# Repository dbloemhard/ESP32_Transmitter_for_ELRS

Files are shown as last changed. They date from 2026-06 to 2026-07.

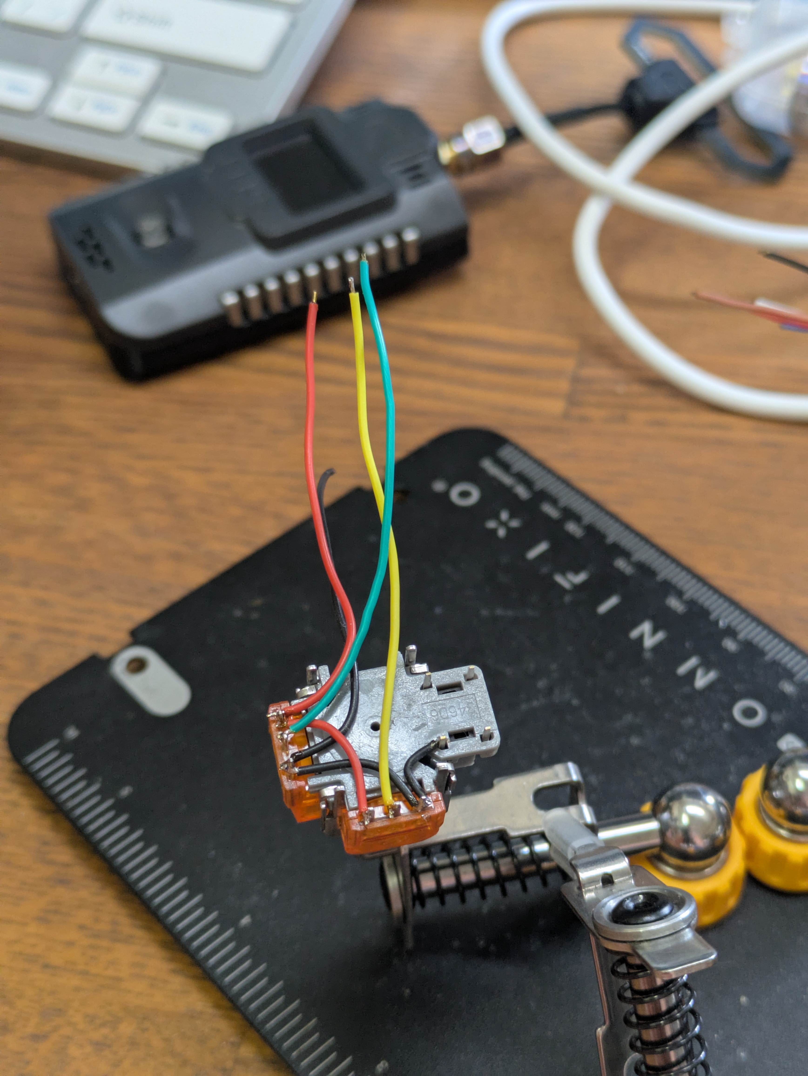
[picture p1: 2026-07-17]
Assets/Joystick Wiring 5.jpg

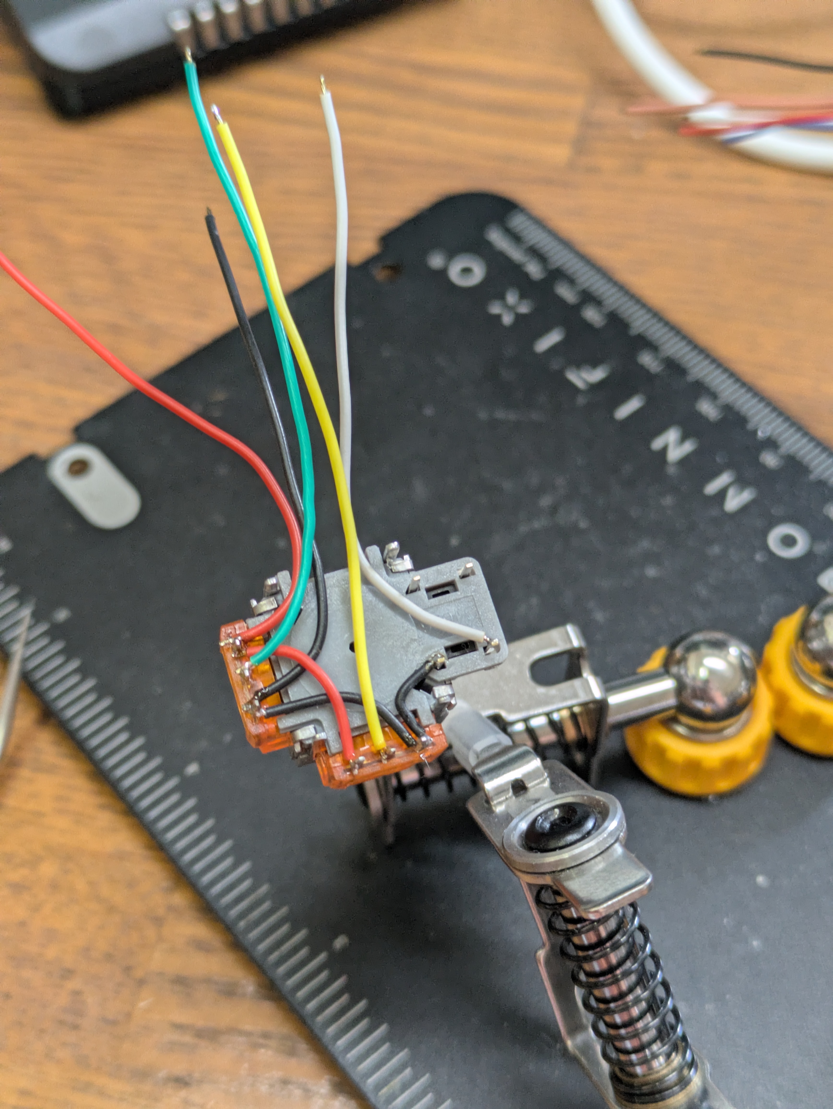
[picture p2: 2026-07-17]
Assets/Joystick Wiring 6.jpg

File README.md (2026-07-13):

# ESP32 C3 Nano TX


ESP32 C3 Nano sized ExpressLRS transmitter originally based on the Simple TX Arduino Transmitter project, with a few extra features.

Simple TX is an Arduino based ELRS RC transmitter TX by Kkbin505. He designed an RC transmitter (soft and hardware) that is simple to build, and use.

I am rewriting it to run on an ESP32 C3. This has an OLED screen and is small enough to make my TinyTX project even smaller. I am reading telemetry from the ELRS module and implemented the full ELRS Lua script for configuring ELRS as well as the handset.

# THIS IS A W.I.P.
https://youtube.com/shorts/-rPwNI36CTY?feature=share

The radio works, and i have flown around my room with it. ELRS transmitter telemetry is working, and the configuration menu is usable to change ELRS settings. Version 3 of the 3D print finally fits everything and can be screwed together using m1.2x6 whoop canopy screws. From here on in its mainly going to be code bug fixes, and maybe i'll come up with another 3d print design.

Currently outstanding code tasks:
* Bluetooth joystick using ESP32-BLE-Gamepad library (RX as a TX does not suport BLE Joystick so need to implement it myself)
* Multitask the OLED updates to free up more time for the ELRS code
* ~~Bluetooth transmitter?? Connect bluetooth joysticks to this device and forward controls to the ELRS transmitter~~ Unfortunately most game controllers use full bluetooth which is only supported on the original ESP32, not the C3

Programmed in Arduino IDE with love and a some AI suggestions (found myself rewriting everything it did). 
1. Install the ESP32 Boards via board manager
2. then select ESP32C3 Dev Module board
3. USB CDC On Boot "Enabled"
4. Build and upload.

# Features:
- Fits in your pocket. Not like the Radio Master Pocket which will get you funny looks... Actually pocketable.
- Using PS5 hall sensor joysticks so you dont miss out on that super magnetic accuracy even at this size.
- 0.42" OLED screen with easy to read, simple display
- Runs on a 1s lipo battery - the same as you fly your whoops with. Have not tested but expect more than 1hr runtime with a  1s 300mah
- Designed to use a 100mw telemetry Nano receiver as a TX module (RX as a TX). Also support ExpressLRS 2.4G external TX modules, but that would probably be bigger than the radio itself. External modules would need a separate power supply as most are designed to work on 7v+
- Up to 500Hz packet rate. Possibly even FLRC 1000hz? Who even uses that...
- 4 analog channels
- 3 AUX channels selectable via joystick button presses (left joystick button toggles Arm, right joystick button toggles channel 6, long press for channel 7)

Current STL is basic, and a tight fit. Make sure all wires are as short as needed, trim as necessary. I will be designing a PCB board you can order from PCBWay or whatever that will make building this a 15 minute job. But for now its manual wiring. 

# Parts list:
* ESP32 C3 with Oled https://ja.aliexpress.com/item/1005009157602185.html
* PS5 Joysticks https://ja.aliexpress.com/item/1005006282848536.html
* Nano receiver to be used as TX module https://ja.aliexpress.com/item/1005010228737836.html?
* 5V boost converter: https://ja.aliexpress.com/item/1005011803028198.html
* Also need two resistors for a voltage divider circuit (16k and 33k), silicone wires, battery pigtail, and a 3D printed case (joystick covers can be printed or bought)
Total cost is around $15-20

Based on work by kkbin505 with his SimpleTX project, but is now almost completely rewritten, 90% by hand (LLMs only used for code suggestions)
 * This project is distributed in the hope that it will be useful, but WITHOUT ANY WARRANTY.

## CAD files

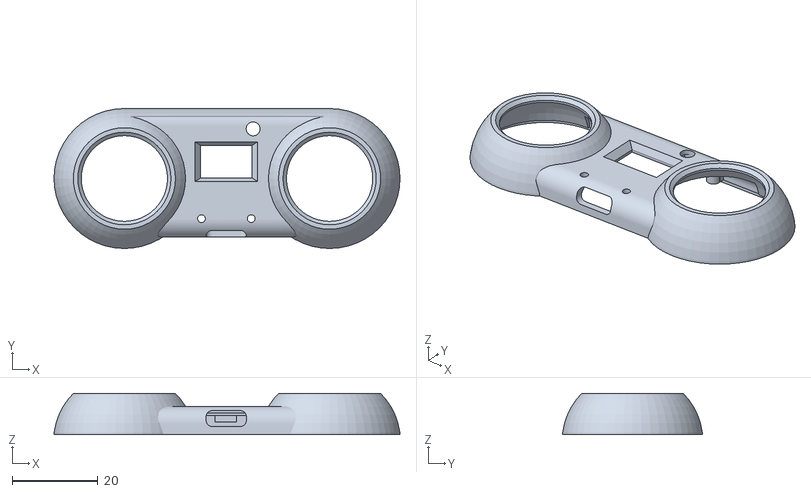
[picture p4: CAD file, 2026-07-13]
Assets/NanoTX Top 3.stl
80.8 x 32.7 x 9.60

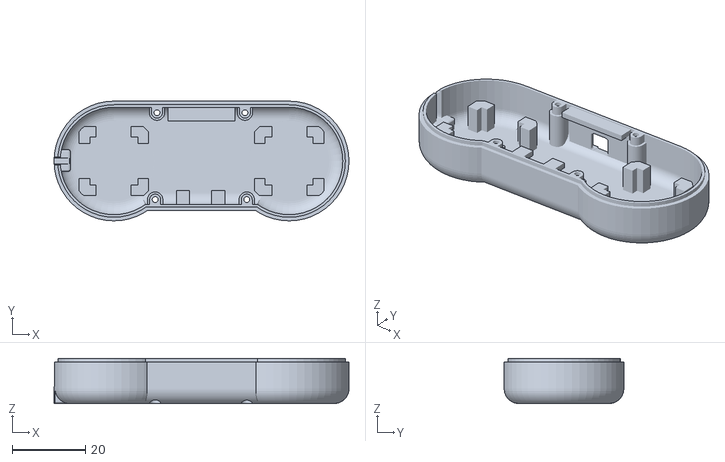
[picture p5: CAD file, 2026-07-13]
Assets/NanoTX Bottom 3.stl
80.8 x 32.8 x 12.4

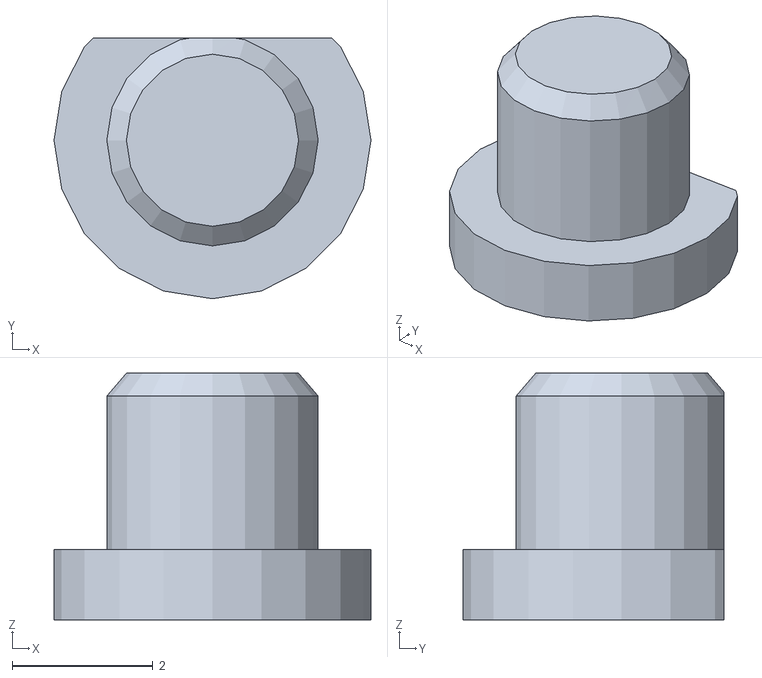
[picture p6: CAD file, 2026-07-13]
Assets/NanoTX Button 3.stl
4.50 x 3.70 x 3.50

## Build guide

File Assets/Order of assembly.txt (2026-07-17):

NanoTX assembly:
-------------------
a. First flash your ELRS receiver to be a transmitter. 
Connect it up to a flight controller, or USB-TTL
Go to https://expresslrs.github.io/web-flasher/ and select Receiver.
Follow normal instructions, most this size will be the Betafpv Nano 2.4Ghz FW
On the Options screen, select Advanced and select "Flash RX as a TX (full duplex internal module only)
Follow other flashing options as normal.
b. Next flash the ESP32 with my firmware. This is coded in Arduino studio so you will need that, as well as the ESP32 library, U8G2 library.
c. Solder the parts together.
--------------------
1. Mock up gimbal distances to know how long to trim the wires before attaching to the ESP32
2. Ditto for the ELRS receiver and 5v regulator
3. ELRS receiver (TX Module) is double-sided taped to the back shell of the housing
4. ELRS antenna is fed through the hole at the top and attached to the receiver (TX Module). It should make a little loop to have some slack.
5. 5V regulator (Shrink wrapped) goes next. It is sandwiched between the receiver and ESP32 - doesn't need tape
6. ESP32 should sit on top of the print without too much pressure needed to push it against the shelves it will sit on. Wires should be tucked in the gap under the ESP32 - the joystick caps will come within 0.5mm of the ESP32 so it is important that all wires are within the bounds of the ESP32 PCB

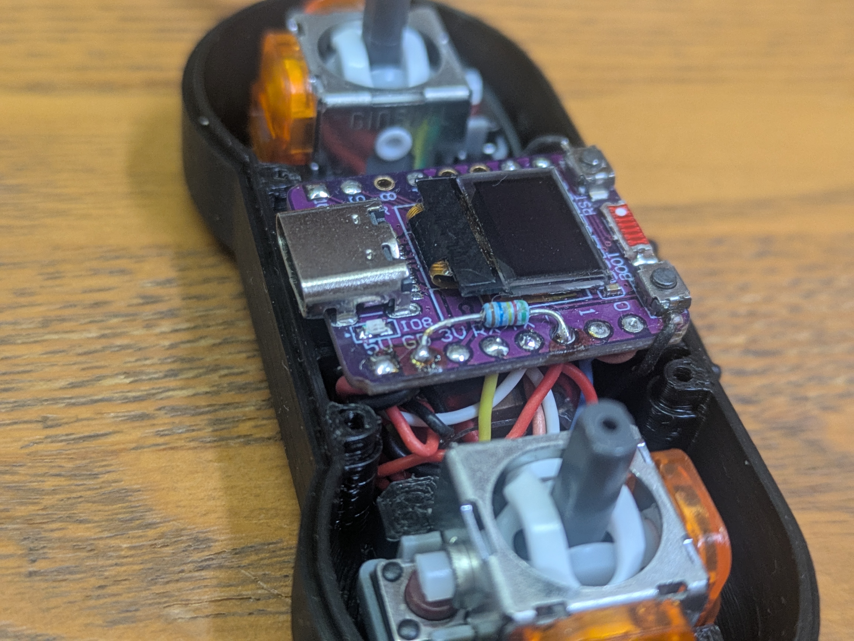
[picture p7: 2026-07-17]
Assets/Ready for Assembly 2.jpg

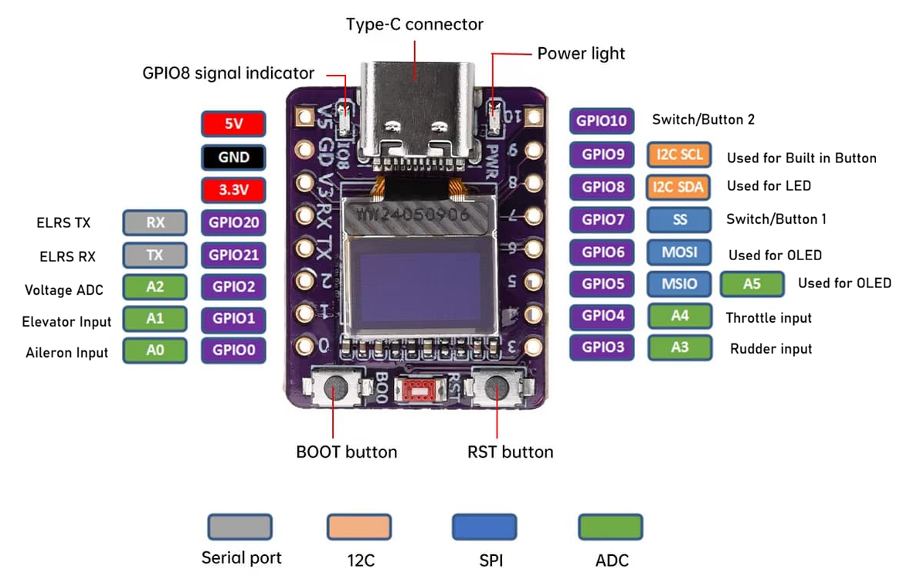
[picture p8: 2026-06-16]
Assets/Wiring Diagram.png

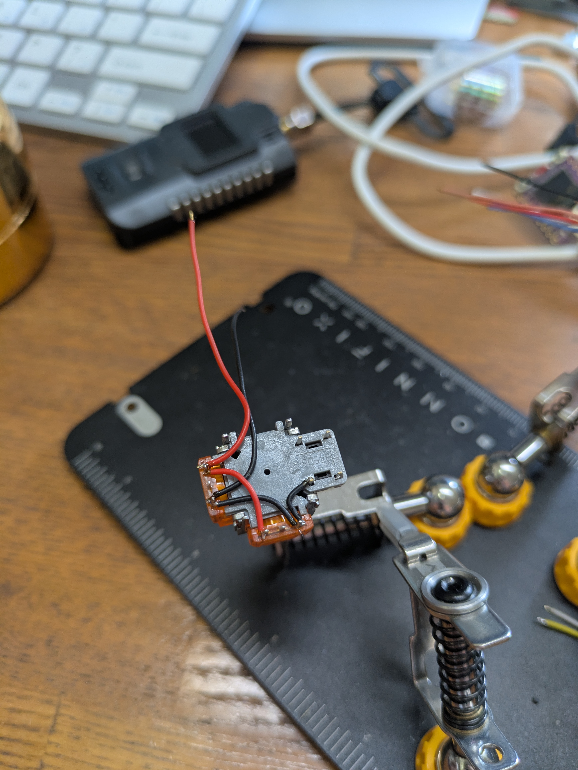
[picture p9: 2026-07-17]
Assets/Joystick Wiring 4.jpg

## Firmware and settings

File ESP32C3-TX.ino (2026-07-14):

/*
// Simple ESP32 C3 transmitter
// ESP32 C3 0.42" OLED
// ELRS 2.4G NANO RX as a TX module
// Based on SimpleTX by kkbin505
// https://github.com/kkbin505/Arduino-Transmitter-for-ELRS

 * This file is part of ESP32C3-TX
 *
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
 * ESP32C3-TX is distributed in the hope that it will be useful,
 * but WITHOUT ANY WARRANTY; without even the implied warranty of
 * MERCHANTABILITY or FITNESS FOR A PARTICULAR PURPOSE.  See the
 * GNU General Public License for more details.
 * <http://www.gnu.org/licenses/>.
 */

#include <Arduino.h>
#include <Preferences.h>
#include "hardware.h"
#include "config.h"
#include "crsf.h"
#include "elrs.h"
#include "oled.h"

//#define DEBUG // if not commented out, Serial.print() is active! For debugging only!!
//#define TIMINGDEBUG  // When this is active Serial port will print out timing details

//----- global variables for inputs -------------------
struct InputValues {
    int32_t leftX;
    int32_t leftY;
    int32_t rightX;
    int32_t rightY;
    int16_t AUX1;
    int16_t AUX2;
    int16_t AUX3;
};
InputValues stickValues;

struct ADCValues {
    int32_t leftX;
    int32_t leftY;
    int32_t rightX;
    int32_t rightY;
    int32_t voltage;
};
ADCValues rawValues;

struct FilterState {
    int32_t rightX;
    int32_t rightY;
    int32_t leftY;
    int32_t leftX;
};
FilterState filteredRaw;

float batteryVoltage;

bool ARMED = false;

// 0 = No move/button
// 1 = Up
// 2 = Down
// 3 = Left
// 4 = Right
// 5 = Joystick button
// 6 = Built in button (short press)
// 7 = Built in button (long press)
uint8_t navigate = 0;

//----- function headers ----------------------------------
inline int32_t lowLatencyFilter(int32_t currentRaw, int32_t *previousFiltered);
int16_t calibrate(int16_t raw, int16_t minVal, int16_t centerVal, int16_t maxVal);
int32_t applyCyclicExpo(int32_t stickDiff, uint8_t expoFactor);
int32_t applyThrottleExpo(int32_t adcVal, uint8_t expoFactor);
uint16_t processStick(int32_t adcValue, uint8_t chIndex);
void mapChannels();
void getAnalogInputs();
void getDigitalInputs();
void checkGestureSetting();
bool checkStickMove();
void playTone(uint8_t timesPerSecond);
void blinkLED(int ledPin, uint16_t blinkRate);
void stickMenuNavigation();
void statusDisplay();
void logData();

//----- global variables for ELRS -------------------------
int16_t rcChannels[CRSF_MAX_CHANNEL];
CRSF crsfClass;
// Instantiate ELRS (Module) class, passing CRSF driver object to it
ELRS elrsClass(crsfClass);

// -----------------------------------------------------------------------------------------------------
// Calibration functions
// -----------------------------------------------------------------------------------------------------
void calibrationLoad();
void calibrationSave();
void calibrationChirp(uint8_t times);
bool calibrationRun();

Preferences prefs;
#define CALIB_CENT_TMO  5000    //ms
#define CALIB_MOVE_TMO  15000   // ms
bool calibrationRequested=false;
uint32_t calibrationTimerStart;
int      cal_reset = 0 ;

struct CalibValues {
    int rightXMin  = 0;
    int rightXMax  = 4095;
    int rightXMid  = 2048;
    int rightYMin  = 0;
    int rightYMax  = 4095;
    int rightYMid  = 2048;
    int leftXMin   = 0;
    int leftXMax   = 4095;
    int leftXMid   = 2048;
    int leftYMin   = 0;
    int leftYMax   = 4095;
    int leftYMid   = 2048;
};
CalibValues calValues;

void calibrationSave() {
    // Open the "gimbal" namespace in Read-Write mode (false)
    prefs.begin("gimbal", false);
    
    prefs.putShort("rightXMin",  calValues.rightXMin);
    prefs.putShort("rightXMid", calValues.rightXMid);
    prefs.putShort("rightXMax",  calValues.rightXMax);
    
    prefs.putShort("rightYMin",  calValues.rightYMin);
    prefs.putShort("rightYMid", calValues.rightYMid);
    prefs.putShort("rightYMax",  calValues.rightYMax);
    
    prefs.putShort("leftXMin",  calValues.leftXMin);
    prefs.putShort("leftXMid", calValues.leftXMid);
    prefs.putShort("leftXMax",  calValues.leftXMax);

    prefs.putShort("leftYMin",  calValues.leftYMin);
    prefs.putShort("leftYMid",  calValues.leftYMid);
    prefs.putShort("leftYMax",  calValues.leftYMax);
        
    prefs.end();
}

void calibrationLoad() {
    // Open the "gimbal" namespace in Read-Only mode
    prefs.begin("gimbal", true);
    
    // Read values, providing safe defaults if no data has been saved yet
    calValues.rightXMin = prefs.getShort("rightXMin", 0);
    calValues.rightXMid = prefs.getShort("rightXMid", 2048);
    calValues.rightXMax = prefs.getShort("rightXMax", 4095);
    
    calValues.rightYMin = prefs.getShort("rightYMin", 0);
    calValues.rightYMid = prefs.getShort("rightYMid", 2048);
    calValues.rightYMax = prefs.getShort("rightYMax", 4095);
    
    calValues.leftXMin  = prefs.getShort("leftXMin", 0);
    calValues.leftXMid  = prefs.getShort("leftXMid", 2048);
    calValues.leftXMax  = prefs.getShort("leftXMax", 4095);
    
    calValues.leftYMin  = prefs.getShort("leftYMin", 0);
    calValues.leftYMid  = prefs.getShort("leftYMid", 2048);
    calValues.leftYMax  = prefs.getShort("leftYMax", 4095);
    
    prefs.end();

}

//Flash LED and beep for (times)
void calibrationChirp(uint8_t times) {
    
    digitalWrite(DIGITAL_PIN_LED, HIGH);
    delay(500);
    digitalWrite(DIGITAL_PIN_LED, LOW);
    delay(500);

    for (uint8_t i = 0; i < times; i++) {
        //tone(DIGITAL_PIN_BUZZER,5000,100);
        digitalWrite(DIGITAL_PIN_LED, HIGH);
        delay(100);
        //digitalWrite(DIGITAL_PIN_BUZZER, LOW);
        digitalWrite(DIGITAL_PIN_LED, LOW);
        delay(100);
    }
    digitalWrite(DIGITAL_PIN_LED, LOW);
}

bool calibrationRun() {
    if (ARMED){
        Serial.println("Cannot calibrate while arm switch is active");
        cal_reset = 0;
        calibrationRequested = false;
        delay(1000);
        return false;
    }

    // Reset variables to "centers"
    while(cal_reset<1){
    Serial.println("Starting Calibration");
    drawCalibrationScreen(1,0);  // OLED display update
    calibrationChirp(2);    // start calibration
    calibrationTimerStart = millis();
    calValues.rightXMin = 65535;
    calValues.rightXMax = 0;
    calValues.rightXMid = 0;
    calValues.rightYMin = 65535;
    calValues.rightYMax = 0;
    calValues.rightYMid = 0;
    calValues.leftXMin  = 65535;
    calValues.leftXMax  = 0;
    calValues.leftXMid  = 0;
    calValues.leftYMin  = 65535;
    calValues.leftYMax  = 0;
    calValues.leftYMid  = 0;
    cal_reset++;
    }

    uint32_t currentMillis = millis();

    if (currentMillis <= (calibrationTimerStart + CALIB_CENT_TMO)){
        // A Center
        int val = analogRead(STICK_RIGHT_X);
        calValues.rightXMid = val;
        
        // E Center
        val = analogRead(STICK_RIGHT_Y);
        calValues.rightYMid = val;

        // T Center
        val = analogRead(STICK_LEFT_Y);
        calValues.leftYMid = val;
    
        // R Center
        val = analogRead(STICK_LEFT_X);
        calValues.leftXMid = val;
 
        drawCalibrationScreen(2,((int)(calibrationTimerStart + CALIB_CENT_TMO - currentMillis)/1000)+1);  // OLED display update

        Serial.print("Center All Sticks:   Aileron Center:");
        Serial.print(calValues.rightXMid);
        Serial.print(" Elevator Center:");
        Serial.print(calValues.rightYMid);
        Serial.print(" Throttle Center:");
        Serial.print(calValues.leftYMid);
        Serial.print(" Rudder Center:");
        Serial.print(calValues.leftXMid);
        Serial.println();

        blinkLED(DIGITAL_PIN_LED, 1000);  // Slow flash while centering
        
    }
    // 15 seconds for moving sticks
    else if (currentMillis > (calibrationTimerStart + CALIB_CENT_TMO) && currentMillis <  (calibrationTimerStart + CALIB_MOVE_TMO)){
        // A Min-Max
        int val = analogRead(STICK_RIGHT_X);
        if (val < calValues.rightXMin) {
            calValues.rightXMin = val;
        } 
        if (val > calValues.rightXMax) {
            calValues.rightXMax = val;
        }
        // E Min-Max
        val = analogRead(STICK_RIGHT_Y);
        if (val < calValues.rightYMin) {
            calValues.rightYMin = val;
        } 
        if (val > calValues.rightYMax) {
            calValues.rightYMax = val;
        }

        // T Min-Max
        val = analogRead(STICK_LEFT_Y);
        if (val < calValues.leftYMin) {
            calValues.leftYMin = val;
        } 
        if (val > calValues.leftYMax) {
            calValues.leftYMax = val;
        }

        // R Min-Max
        val = analogRead(STICK_LEFT_X);
        if (val < calValues.leftXMin) {
            calValues.leftXMin = val;
        } 
        if (val > calValues.leftXMax) {
            calValues.leftXMax = val;
        }

        drawCalibrationScreen(3,((int)(calibrationTimerStart + CALIB_MOVE_TMO - currentMillis)/1000)+1);  // OLED display update

        Serial.print("Move sticks full range: Aileron Min:");
        Serial.print(calValues.rightXMin);
        Serial.print(" Max:");
        Serial.print(calValues.rightXMax);
        Serial.print(" Elevator Min:");
        Serial.print(calValues.rightYMin);
        Serial.print(" Max:");
        Serial.print(calValues.rightYMax);
        Serial.print(" Rudder Min:");
        Serial.print(calValues.leftXMin);
        Serial.print(" Max:");
        Serial.print(calValues.leftXMax);
        Serial.print(" Throttle Min:");
        Serial.print(calValues.leftYMin);
        Serial.print(" Max:");
        Serial.print(calValues.leftYMax);
        Serial.println();

        blinkLED(DIGITAL_PIN_LED, 100);  // Fast flash while moving to limits
    }
    else {
        Serial.println("Calibration Done");  
        calibrationSave();

        drawCalibrationScreen(4,0);  // OLED display update

        cal_reset = 0;
        calibrationRequested = false;
        calibrationChirp(3);    // ok
        lastScreen = CALIBRATION;
    }
    return true;

}

// -----------------------------------------------------------------------------------------------------
// Handle analog input
// -----------------------------------------------------------------------------------------------------
void getAnalogInputs() {
    // Read Voltage
    rawValues.voltage = analogRead(ANALOG_PIN_VOLTAGE);
    batteryVoltage = (float)rawValues.voltage / VOLTAGE_SCALE;

    // 1. Read raw 12-bit ADC values (0 - 4095)
    int32_t currentRightX = analogRead(STICK_RIGHT_X);
    int32_t currentRightY = analogRead(STICK_RIGHT_Y);
    int32_t currentLeftY  = analogRead(STICK_LEFT_Y);
    int32_t currentLeftX  = analogRead(STICK_LEFT_X);
    
    // 2. Apply fast IIR filter to raw hardware values (if enabled in globalSettings)
    rawValues.rightX = lowLatencyFilter(currentRightX, &filteredRaw.rightX);
    rawValues.rightY = lowLatencyFilter(currentRightY, &filteredRaw.rightY);
    rawValues.leftY  = lowLatencyFilter(currentLeftY,  &filteredRaw.leftY);
    rawValues.leftX  = lowLatencyFilter(currentLeftX,  &filteredRaw.leftX);
    
    // 3. Apply calibration mappings
    stickValues.rightX = calibrate(rawValues.rightX, calValues.rightXMin, calValues.rightXMid, calValues.rightXMax);
    stickValues.rightY = calibrate(rawValues.rightY, calValues.rightYMin, calValues.rightYMid, calValues.rightYMax);
    stickValues.leftY  = calibrate(rawValues.leftY,  calValues.leftYMin, calValues.leftYMid, calValues.leftYMax);
    stickValues.leftX  = calibrate(rawValues.leftX,  calValues.leftXMin, calValues.leftXMid, calValues.leftXMax);

    // 4. Hard-coded reverse (Gimbal configuration)
    #ifdef AILERON_REVERSE
        stickValues.rightX  = ADC_MAX-stickValues.rightX;
    #endif
    #ifdef ELEVATOR_REVERSE
        stickValues.rightY = ADC_MAX-stickValues.rightY;
    #endif
    #ifdef THROTTLE_REVERSE
        stickValues.leftY = ADC_MAX-stickValues.leftY;
    #endif
    #ifdef RUDDER_REVERSE
        stickValues.leftX   = ADC_MAX-stickValues.leftX;
    #endif

    // 5. Check if the current movement qualifies for menu navigation
    stickMenuNavigation();

}

// Use right joystick for menu navigation
// Moving past the threshold (50% throw) will move once in that direction
// Go back below the threshold for 100ms before you can initiate another move in any direction
void stickMenuNavigation() {
    // Timers for filtering noise (debouncing)
    static uint32_t centerStartTime = 0;
    static uint32_t deflectionStartTime = 0;
    
    // State tracking variables
    static bool isCentered = true;       // True if joystick is confirmed at center
    static bool hasNavigated = false;    // Prevents continuous triggers while holding
    static uint8_t pendingDirection = 0; // Temporarily stores the direction being debounced

    uint32_t currentMillis = millis();
    navigate = 0; // Reset navigate variable at the start of each loop

    // Check if joystick is currently physically in the center zone
    bool stickCentered = (stickValues.rightY > RC_MIN_COMMAND && stickValues.rightY < RC_MAX_COMMAND &&
                               stickValues.rightX  > RC_MIN_COMMAND && stickValues.rightX  < RC_MAX_COMMAND);

    // Handle Center Debouncing
    if (stickCentered) {
        deflectionStartTime = 0; // Reset deflection timer
        if (centerStartTime == 0) {
            centerStartTime = currentMillis; // Start center debounce timer
        } else if (currentMillis - centerStartTime >= shortPressDuration) {
            isCentered = true;   // Joystick is officially centered
            hasNavigated = false; // Reset navigation lock for the next movement
        }
    } 
    // Handle Deflection Debouncing & Navigation
    else {
        centerStartTime = 0; // Reset center timer
        
        // Determine current physical direction of deflection
        uint8_t currentDirection = 0;
        if (stickValues.rightY >= RC_MAX_COMMAND)       currentDirection = 1; // Up
        else if (stickValues.rightY <= RC_MIN_COMMAND)  currentDirection = 2; // Down
        else if (stickValues.rightX <= RC_MIN_COMMAND)  currentDirection = 3; // Left
        else if (stickValues.rightX >= RC_MAX_COMMAND)  currentDirection = 4; // Right

        // If the direction changed mid-deflection, reset the deflection timer
        if (currentDirection != pendingDirection) {
            deflectionStartTime = currentMillis;
            pendingDirection = currentDirection;
        } 
        // If held in the same direction for long enough, check if we can navigate
        else if (currentMillis - deflectionStartTime >= shortPressDuration) {
            if (isCentered && !hasNavigated) {
                navigate = pendingDirection; // Trigger the menu action
                hasNavigated = true;         // Lock execution until center return
                isCentered = false;          // No longer marked as centered
            }
        }
    }
}

// ADC Filtering, since ESP32 ADCs are supposed to be noisy
inline int32_t lowLatencyFilter(int32_t currentRaw, int32_t *previousFiltered) {
    if (globalSettings.adcFilter && *previousFiltered > 0) {
        // IIR Filter implementation using fast integer bit-shifting:
        // NewFiltered = PreviousFiltered + ((CurrentRaw - PreviousFiltered) >> FILTER_SHIFT)
        *previousFiltered = *previousFiltered + ((currentRaw - *previousFiltered) >> FILTER_SHIFT);
    }
    else {
        *previousFiltered = currentRaw;
    }
    return *previousFiltered;
}

// Calibration maps top and bottom parts of stick deflections separately to account for uneven ADC ranges
int16_t calibrate(int16_t raw, int16_t minVal, int16_t centerVal, int16_t maxVal) {
    raw = constrain(raw, minVal, maxVal);
    
    if (raw <= centerVal) {
        // Map lower half of stick deflection 
        return map(raw, minVal, centerVal, ADC_MIN, ADC_MID);
    } else {
        // Map upper half of stick deflection
        return map(raw, centerVal, maxVal, ADC_MID+1, ADC_MAX);
    }
}

// Expo function for Aileron, Elevator, Rudder (Zero-Centered: -1024 to +1024)
int32_t applyCyclicExpo(int32_t stickDiff, uint8_t expoFactor) {
    if (expoFactor == 0) return stickDiff;
    int32_t stickCubed = (stickDiff * stickDiff * stickDiff) >> 20; 
    return ((100 - expoFactor) * stickDiff + expoFactor * stickCubed) / 100;
}

// For Throttle (Full Range: 0 to 2047)
int32_t applyThrottleExpo(int32_t adcVal, uint8_t expoFactor) {
    if (expoFactor == 0) return adcVal;
    // Shift down to 0-1023 to avoid 32-bit integer overflow during cubing
    int32_t downscaled = adcVal >> 1; 
    int32_t cubed = (downscaled * downscaled * downscaled) >> 20; // 0 to 1023
    int32_t throttleCubed = cubed << 1; // Scale back up to 0-2047
    return ((100 - expoFactor) * adcVal + expoFactor * throttleCubed) / 100;
}
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
void loop()
{
    static uint32_t crsfTime = 0;
#ifdef TIMINGDEBUG
    static uint32_t nextLogTimeUs = 0;
    uint32_t nowUs = micros();

    if (nextLogTimeUs = 0) nextLogTimeUs = nowUs + 4000;
    loopCounter++;
    if (nowUs >= nextLogTimeUs) {
        startLoopUs = micros();
    }
#endif
    // Calibration (if requested)
    if (calibrationRequested)
        calibrationRun();
    else {
        // Get the gimbal stick values
        getAnalogInputs();

        // Read AUX channels and buttons
        getDigitalInputs();

        // Check for quick settings change via arm toggle gesture
        checkGestureSetting(); 
        
        mapChannels();

#ifdef DEBUG        
        // Debug data
        logData();
#endif
 
        // ---------------------------------------------------------------------------
        // Read Telemetry data every loop (telemetry processed in crsfCheckTelemetry)
        crsfClass.crsfReadTelemetry();

        // -------------------------------------------------
        // Poll the telemetry data and run lua script logic
        elrsClass.update(currentScreen == ELRS_MENU);       

        // --------------------------------
        // Send RC data to external module
        uint32_t currentMicros = micros();
        if (currentMicros > crsfTime) {
            // Command packet interleaving
            if (crsfClass.commandQueue.hasItems()) {
                crsfClass.crsfSendQueuedCommand();
            } else {
                crsfClass.crsfSendChannels(rcChannels);
            }

#ifdef TIMINGDEBUG
            uint32_t elrsTime = micros() - currentMicros;
            if (elrsTime > maxElrsTime) maxElrsTime = elrsTime;
            if (elrsTime < minElrsTime) minElrsTime = elrsTime;
#endif
            uint32_t adjustment = crsfClass.crsfNextInterval();
            crsfTime = currentMicros + adjustment; //CRSF_TIME_BETWEEN_FRAMES_US;
#ifdef DEBUG
            if (millis() - lastSyncPrintTime > 2000) {
                Serial.println("\n============ [Loop timing] ============");
                Serial.print("Next Interval : "); Serial.print(adjustment); Serial.println(" microseconds");
                Serial.println("=======================================");
                lastSyncPrintTime = millis();
            }
#endif
        }

#ifdef TIMINGDEBUG
        uint32_t oledStartTime = micros();
#endif  

        // Update OLED display, flash led and use beeper
        statusDisplay();

#ifdef TIMINGDEBUG
        uint32_t oledTime = micros() - oledStartTime;
        if (oledTime > maxOledTime) maxOledTime = oledTime;
        if (oledTime < minOledTime) minOledTime = oledTime;
        cumOledTime += oledTime;
        cntOledRuns++;
#endif

    } // Not calibrating
#ifdef TIMINGDEBUG
    if (nowUs >= nextLogTimeUs) {
        uint32_t elapsedUs = micros() - startLoopUs;
        if (elapsedUs > maxLoopTime) maxLoopTime = elapsedUs;
        if (elapsedUs < minLoopTime) minLoopTime = elapsedUs;
        totalTransmitFrames++;

        nextLogTimeUs += 4000; 
    }
    // ---------------------------------------------------------------------------
    if (millis() - lastStatsPrintTime > 5000) {
        lastStatsPrintTime = millis();      
        Serial.println("\n============ [HANDSET PERFORMANCE METRICS] ============");
        Serial.print("Max Loop Duration : "); Serial.print(maxLoopTime); Serial.println(" microseconds");
        Serial.print("Min Loop Duration : "); Serial.print(minLoopTime); Serial.println(" microseconds");
        Serial.print("Avg Loop Duration : "); Serial.print(5000000/totalTransmitFrames); Serial.println(" microseconds");
        Serial.print("Total Transmit Frames   : "); Serial.println(totalTransmitFrames);
        Serial.print("Max OLED Duration : "); Serial.print(maxOledTime); Serial.println(" microseconds");
        Serial.print("Min OLED Duration : "); Serial.print(minOledTime); Serial.println(" microseconds");
        Serial.print("Avg OLED Duration : "); Serial.print(cumOledTime/cntOledRuns); Serial.println(" microseconds");
        Serial.print("Total ELRS Frames   : "); Serial.println(loopCounter);
        Serial.print("Max ELRS Duration : "); Serial.print(maxElrsTime); Serial.println(" microseconds");
        Serial.print("Min ELRS Duration : "); Serial.print(minElrsTime); Serial.println(" microseconds");
        Serial.print("Avg ELRS Duration : "); Serial.print(5000000/loopCounter); Serial.println(" microseconds");
        Serial.print("Total ELRS Frames   : "); Serial.println(loopCounter);
        Serial.println("=======================================================");
        
        // Reset max peak-hold values to check for performance dips in the next window
        maxLoopTime = 0;
        minLoopTime = 0;
        maxElrsTime = 0;
        minElrsTime = 0;
        totalTransmitFrames = 0;
        loopCounter = 0;
    }    
#endif
}

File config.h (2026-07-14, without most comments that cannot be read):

#pragma once
/*
 * This file is part of ESP32C3-TX
 *
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
 * ESP32C3-TX is distributed in the hope that it will be useful,
 * but WITHOUT ANY WARRANTY; without even the implied warranty of
 * MERCHANTABILITY or FITNESS FOR A PARTICULAR PURPOSE.  See the
 * GNU General Public License for more details.
 * <http://www.gnu.org/licenses/>.
 */
 
#include "params.h"

//#define USE_M7

/*
 =======================================================================================================
 Simple TX CONFIG OPTIONS (comment out unneeded options)
 =======================================================================================================
 */
// Define hard-coded gimbal reverse (uncomment to reverse that channel) - can also be configured in handset settings
#define AILERON_REVERSE
//#define ELEVATOR_REVERSE
#define THROTTLE_REVERSE
//#define RUDDER_REVERSE

// Active buzzer only plays one tone (often used on Flight controllers as a beeper)
// Can also use a vibrator motor
//#define ACTIVE_BUZZER

//----- Voltage monitoring -------------------------
// Define battery warning voltage
const float VOLTAGE_SCALE = 454.5;
const float WARNING_VOLTAGE = 3.7; // 1S Lipo 3.7v per cell
const float BEEPING_VOLTAGE = 3.5; // 1S Lipo 3.5v per cell
const float ON_USB = 1.0;          // On USB power / no battery

#define AUX_LONG_PRESS 1000               // default 1s press for enabling/disabling aux 3 (can be changed in handset settings)
const uint32_t longPressDuration = 1500;  // Used for long press of builtin button
const uint32_t shortPressDuration = 100;  // Used for debounce of builtin/joystick buttons

// Define Commond for start Up Setting
// ~50% stick deflection
#define RC_MIN_COMMAND 511
#define RC_MAX_COMMAND 1535

// Define stick idle alarm time
#define STICK_ALARM_TIME 300000 // 300s or 5 minutes

// Define analog input limits. ESP32 supports 12-bit resolution (0 - 4095), but in reality only half of that is useable
#define ADC_MIN 0
#define ADC_MID 1023
#define ADC_MAX 2047

// Filter coefficient: Higher = smoother but more latency. 
// A value of 2 (shifts by 2) means 25% new raw sample, 75% old history. 
// Value of 3 shifts by 2^3 = 8 means 12.5% new, 87.5% old value
#define FILTER_SHIFT 3

enum ChannelOrder
{
    AILERON,
    ELEVATOR,
    THROTTLE,
    RUDDER,
    AUX1, // (CH5)  ARM switch for Expresslrs
    AUX2, // (CH6)  angel / airmode change
    AUX3, // (CH7)  flip after crash
    AUX4, // (CH8)
    AUX5, // (CH9)
    AUX6, // (CH10)
    AUX7, // (CH11)
    AUX8, // (CH12)
};

struct HandsetSettings {
    uint8_t channelMode;
    bool adcFilter;
    uint16_t deadband;
    uint16_t auxLongPress;
    bool throttleCentered;

    bool reverse[4];  // True = reversed for A, E, T, R
    uint8_t limit[4]; // 0 to 100 (%) for A, E, T, R
    uint8_t expo[4];  // 0 to 100 (%) for A, E, T, R
};
extern HandsetSettings globalSettings;
extern ParamCollection handsetSettingsMenu;

void loadGlobalSettings(bool initialize); // pass in true to rebuild from scratch, false will update existing entries
void saveGlobalSettings();  // Saves the currently selected global settings menu item with the current edit value
void executeSettingsCommand(); // Executes the currently selected command, eg reset all settings. Not currently used.
void populateSettingsMenu();
bool addFolder(int idx, int parent, const char* label) ;
bool addInfo(int idx, int parent, const char* label, const char* valueString);
bool addChoiceParam(int idx, int parent, const char* label, const std::vector<const char*>& choices, int currVal, int min, int max);
bool addNumericParam(int idx, int parent, crsfValueType type, const char* label, int currVal, int min, int max, int step, const char* units);
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

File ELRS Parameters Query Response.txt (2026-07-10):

[ELRS] -> Querying Menu Parameter Index: 0, chunk: 0
Received Packet type 0x2B
Parsing param info packet: EA 19 2B EA EE 0 0 0 B 48 6F 6F 4A 0 1 2 3 4 5 6 9 F 12 13 14 FF A1 
Copied Initial Chunk: EA 19 2B EA EE 0 0 0 B 48 6F 6F 4A 0 1 2 3 4 5 6 9 F 12 13 14 FF A1 
[ELRS] -> Querying Menu Parameter Index: 1, chunk: 0
Received Packet type 0x2B
Parsing param info packet: EA 3E 2B EA EE 1 3 0 9 50 61 63 6B 65 74 20 52 61 74 65 0 35 30 48 7A 28 2D 31 31 35 64 42 6D 29 3B 31 30 30 48 7A 20 46 75 6C 6C 28 2D 31 31 32 64 42 6D 29 3B 31 35 30 48 7A 28 2D 31 8A 
Copied Initial Chunk: EA 3E 2B EA EE 1 3 0 9 50 61 63 6B 65 74 20 52 61 74 65 0 35 30 48 7A 28 2D 31 31 35 64 42 6D 29 3B 31 30 30 48 7A 20 46 75 6C 6C 28 2D 31 31 32 64 42 6D 29 3B 31 35 30 48 7A 28 2D 31 8A 
[ELRS] -> Querying Menu Parameter Index: 1, chunk: 1
Received Packet type 0x2B
Parsing param info packet: EA 3E 2B EA EE 1 2 31 32 64 42 6D 29 3B 32 35 30 48 7A 28 2D 31 30 38 64 42 6D 29 3B 33 33 33 48 7A 20 46 75 6C 6C 28 2D 31 30 35 64 42 6D 29 3B 35 30 30 48 7A 28 2D 31 30 35 64 42 6D 29 E 
Copied Next Chunk: EA 3E 2B EA EE 1 3 0 9 50 61 63 6B 65 74 20 52 61 74 65 0 35 30 48 7A 28 2D 31 31 35 64 42 6D 29 3B 31 30 30 48 7A 20 46 75 6C 6C 28 2D 31 31 32 64 42 6D 29 3B 31 35 30 48 7A 28 2D 31 31 32 64 42 6D 29 3B 32 35 30 48 7A 28 2D 31 30 38 64 42 6D 29 3B 33 33 33 48 7A 20 46 75 6C 6C 28 2D 31 30 35 64 42 6D 29 3B 35 30 30 48 7A 28 2D 31 30 35 64 42 6D 29 E 
[ELRS] -> Querying Menu Parameter Index: 1, chunk: 2
Received Packet type 0x2B
Parsing param info packet: EA 3E 2B EA EE 1 1 3B 44 32 35 30 28 2D 31 30 34 64 42 6D 29 3B 44 35 30 30 28 2D 31 30 34 64 42 6D 29 3B 46 35 30 30 28 2D 31 30 34 64 42 6D 29 3B 46 31 30 30 30 28 2D 31 30 34 64 42 6D E8 
Copied Next Chunk: EA 3E 2B EA EE 1 3 0 9 50 61 63 6B 65 74 20 52 61 74 65 0 35 30 48 7A 28 2D 31 31 35 64 42 6D 29 3B 31 30 30 48 7A 20 46 75 6C 6C 28 2D 31 31 32 64 42 6D 29 3B 31 35 30 48 7A 28 2D 31 31 32 64 42 6D 29 3B 32 35 30 48 7A 28 2D 31 30 38 64 42 6D 29 3B 33 33 33 48 7A 20 46 75 6C 6C 28 2D 31 30 35 64 42 6D 29 3B 35 30 30 48 7A 28 2D 31 30 35 64 42 6D 29 3B 44 32 35 30 28 2D 31 30 34 64 42 6D 29 3B 44 35 30 30 28 2D 31 30 34 64 42 6D 29 3B 46 35 30 30 28 2D 31 30 34 64 42 6D 29 3B 46 31 30 30 30 28 2D 31 30 34 64 42 6D E8 
[ELRS] -> Querying Menu Parameter Index: 1, chunk: 3
Received Packet type 0x2B
Parsing param info packet: EA D 2B EA EE 1 0 29 0 2 0 9 0 0 BD 
Copied Next Chunk: EA 3E 2B EA EE 1 3 0 9 50 61 63 6B 65 74 20 52 61 74 65 0 35 30 48 7A 28 2D 31 31 35 64 42 6D 29 3B 31 30 30 48 7A 20 46 75 6C 6C 28 2D 31 31 32 64 42 6D 29 3B 31 35 30 48 7A 28 2D 31 31 32 64 42 6D 29 3B 32 35 30 48 7A 28 2D 31 30 38 64 42 6D 29 3B 33 33 33 48 7A 20 46 75 6C 6C 28 2D 31 30 35 64 42 6D 29 3B 35 30 30 48 7A 28 2D 31 30 35 64 42 6D 29 3B 44 32 35 30 28 2D 31 30 34 64 42 6D 29 3B 44 35 30 30 28 2D 31 30 34 64 42 6D 29 3B 46 35 30 30 28 2D 31 30 34 64 42 6D 29 3B 46 31 30 30 30 28 2D 31 30 34 64 42 6D 29 0 2 0 9 0 0 BD 
[PARAMETER SAVED] Packet Rate | Choices(0-9): 50Hz(-115dBm), 100Hz Full(-112dBm), 150Hz(-112dBm), 250Hz(-108dBm), 333Hz Full(-105dBm), 500Hz(-105dBm), D250(-104dBm), D500(-104dBm), F500(-104dBm), F1000(-104dBm) | Active Selection: 150Hz(-112dBm)
[ELRS] -> Querying Menu Parameter Index: 2, chunk: 0
Received Packet type 0x2B
Parsing param info packet: EA 3E 2B EA EE 2 1 0 9 54 65 6C 65 6D 20 52 61 74 69 6F 0 53 74 64 3B 4F 66 66 3B 31 3A 31 32 38 3B 31 3A 36 34 3B 31 3A 33 32 3B 31 3A 31 36 3B 31 3A 38 3B 31 3A 34 3B 31 3A 32 3B 52 B8 
Copied Initial Chunk: EA 3E 2B EA EE 2 1 0 9 54 65 6C 65 6D 20 52 61 74 69 6F 0 53 74 64 3B 4F 66 66 3B 31 3A 31 32 38 3B 31 3A 36 34 3B 31 3A 33 32 3B 31 3A 31 36 3B 31 3A 38 3B 31 3A 34 3B 31 3A 32 3B 52 B8 
[ELRS] -> Querying Menu Parameter Index: 2, chunk: 1
Received Packet type 0x2B
Parsing param info packet: EA 16 2B EA EE 2 0 61 63 65 0 0 0 9 0 20 28 31 3A 33 32 29 0 3E 
Copied Next Chunk: EA 3E 2B EA EE 2 1 0 9 54 65 6C 65 6D 20 52 61 74 69 6F 0 53 74 64 3B 4F 66 66 3B 31 3A 31 32 38 3B 31 3A 36 34 3B 31 3A 33 32 3B 31 3A 31 36 3B 31 3A 38 3B 31 3A 34 3B 31 3A 32 3B 52 61 63 65 0 0 0 9 0 20 28 31 3A 33 32 29 0 3E 
[PARAMETER SAVED] Telem Ratio | Choices(0-9): Std, Off, 1:128, 1:64, 1:32, 1:16, 1:8, 1:4, 1:2, Race | Active Selection: Std (1:32)
[ELRS] -> Querying Menu Parameter Index: 3, chunk: 0
Received Packet type 0x2B
Parsing param info packet: EA 25 2B EA EE 3 0 0 9 53 77 69 74 63 68 20 4D 6F 64 65 0 57 69 64 65 3B 48 79 62 72 69 64 0 0 0 1 0 0 83 
Copied Initial Chunk: EA 25 2B EA EE 3 0 0 9 53 77 69 74 63 68 20 4D 6F 64 65 0 57 69 64 65 3B 48 79 62 72 69 64 0 0 0 1 0 0 83 
[PARAMETER SAVED] Switch Mode | Choices(0-1): Wide, Hybrid | Active Selection: Wide
[ELRS] -> Querying Menu Parameter Index: 4, chunk: 0
Received Packet type 0x2B
Parsing param info packet: EA 26 2B EA EE 4 0 0 9 4C 69 6E 6B 20 4D 6F 64 65 0 4E 6F 72 6D 61 6C 3B 4D 41 56 4C 69 6E 6B 0 0 0 1 0 0 6
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

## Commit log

2026-06-13 Initial Commit
    Dummy Display looks nice but the Adafruit display driver is slow, slows down the packets sent to ELRS to under 200hz
2026-06-16 Working Beta
    This code is working and i have now done some test flights.
    Short press left joystick to arm/disarm.
    Short press right joystick to toggle aux2 (angle)
    Long press right joystick to toggle aux3 (turtle mode)
    Button on the ESP32 C3 currently switches between main screen and elrs stats screen.
    Long press to start gimbal calibration (only when disarmed)
    [NanoTX Bottom.stl, NanoTX Button.stl, NanoTX Top.stl]
2026-06-17 Check timing for OLED update
    Added some lines to check OLED transmit times. So far, its not looking good - 8ms to send data to the display means that I will be missing several CRSF timeslots every time that is updated (8% at 10hz...)
    [oled.h]
2026-06-20 Improve OLED performance
    Update the screen via updateDisplayArea instead of just sendBuffer as this takes up to 8ms(!). Now down to 3.5ms for the main screen. Also reduced the update rate to 2hz while armed - to reduce the i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
2026-06-29 Switched to using a stack for loading params
    Using a stack means i can now reload individual items, or the whole lot. This was required to reload the saved values when making changes in the menu!
2026-07-01 Rename main .ino file
    [NanoTX Top 2.stl, NanoTX bottom 2.stl, NanoTX button 2.stl]
2026-07-01 Move assets to their own folder
    STLs and images taken from main folder
    [NanoTX Bottom.stl, NanoTX Button.stl, NanoTX Top 2.stl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]
2026-07-04 Modularize menu
    Decouple the menu functions from the ELRS object; now using a Parameter Collection which is an object which can be reused for a Configuration menu.
    [NanoTX Top 2.stl, NanoTX bottom 2.stl]
2026-07-08 Channel outputs page and menu complete
    Now the menu page displays correctly, settings can be updated. Main page shows stick values. Outputs page shows what is sent to ELRS
    [ELRS Parameters Query Response.txt]
2026-07-13 Minor bug fixes, final 3d print design
    [NanoTX Bottom 3.stl, NanoTX Bottom.stl, NanoTX Button 3.stl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]
2026-07-25 Update STLs
    Updated STLs and a precompiled binary for if you dont want to install Arduino IDE (flash from 0x0000)
2026-08-05 Add BLE Gamepad functionality
    Implement a switchable BLE Gamepad functionality, since RX as a TX does not include BLE Joystick function. Plus this eliminates one point of latency - sticks, direct to the bluetooth stack.
2026-08-05 Create NanoTX gimbal cap - M2 4x4mm Heat insert.stl
2026-08-14 PCB first attempt!
    Finally finished a PCB design. I dont know if this works yet, so order at your own risk. I have ordered my own PCBs and will test them out in a week or 2
2026-08-20 Update README.md with pics of PCB
2026-08-21 Updated STLs
    For the Gimbal Cap, increased the hole size to match the 4x4mm brass M2 inserts i have.
    Added a Spacer to help you get the height of the ESP32 just right
    Updated PCB STLs
2026-09-24 Update README.md
    Updated info about voltage regulator
2026-11-11 Add channel mixing... Sort of.
    I got myself a Kyosho Blizzard SR (tank tracked snow plow) and wanted to control it with the right stick (throttle controls the plow height. So i implemented rudimentary channel mixing. This is hard 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
2026-11-11 Added comments on mixer functionality
    Added comments to explain how the mixer function works - should help understanding how to modify it for other uses such as flying wings.
2026-11-11 Added Kicad files
    Added .kicad_pro, .kicad_sch and .kicad_pcb files to allow people to edit/modify for different parts or designs.

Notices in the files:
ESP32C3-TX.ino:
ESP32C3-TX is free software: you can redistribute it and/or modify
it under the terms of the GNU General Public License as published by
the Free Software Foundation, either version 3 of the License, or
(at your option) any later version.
